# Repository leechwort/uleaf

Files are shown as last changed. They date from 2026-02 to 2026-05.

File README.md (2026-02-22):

# uLEAF

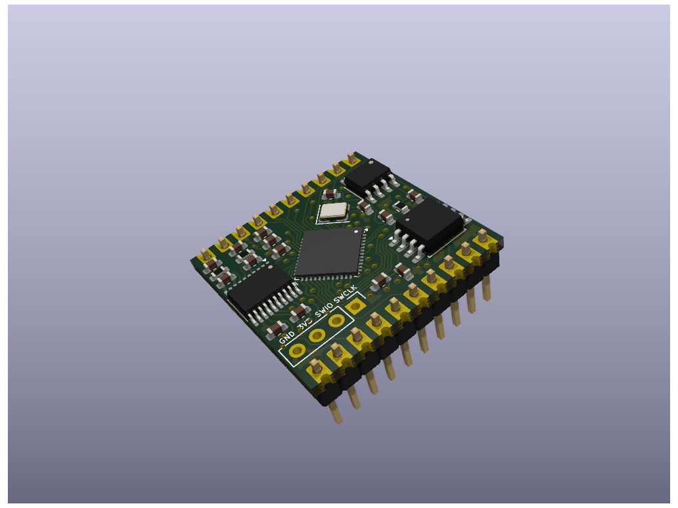
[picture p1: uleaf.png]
uLEAF Development Board


**uLEAF** is a minimalistic STM32 platform for developing audio synthesis applications. It was primarily designed for use with [LEAF (Lightweight Embedded Audio Framework)](https://github.com/spiricom/LEAF), but is not limited to it. 

### Hardware Features
* **Powerful MCU:** Cortex-M33 (STM32H533) with memory-mapped 8 MB PSRAM
* **Storage:** 8 MB additional external Flash memory
* **Audio:** Audio DAC PCM5102A

### Design Philosophy
This development board tries to be as cheap and simple as possible. It is designed to be highly versatile, allowing you to easily embed it directly into your own projects or use it as a starting point to develop your own custom PCB based on this design.

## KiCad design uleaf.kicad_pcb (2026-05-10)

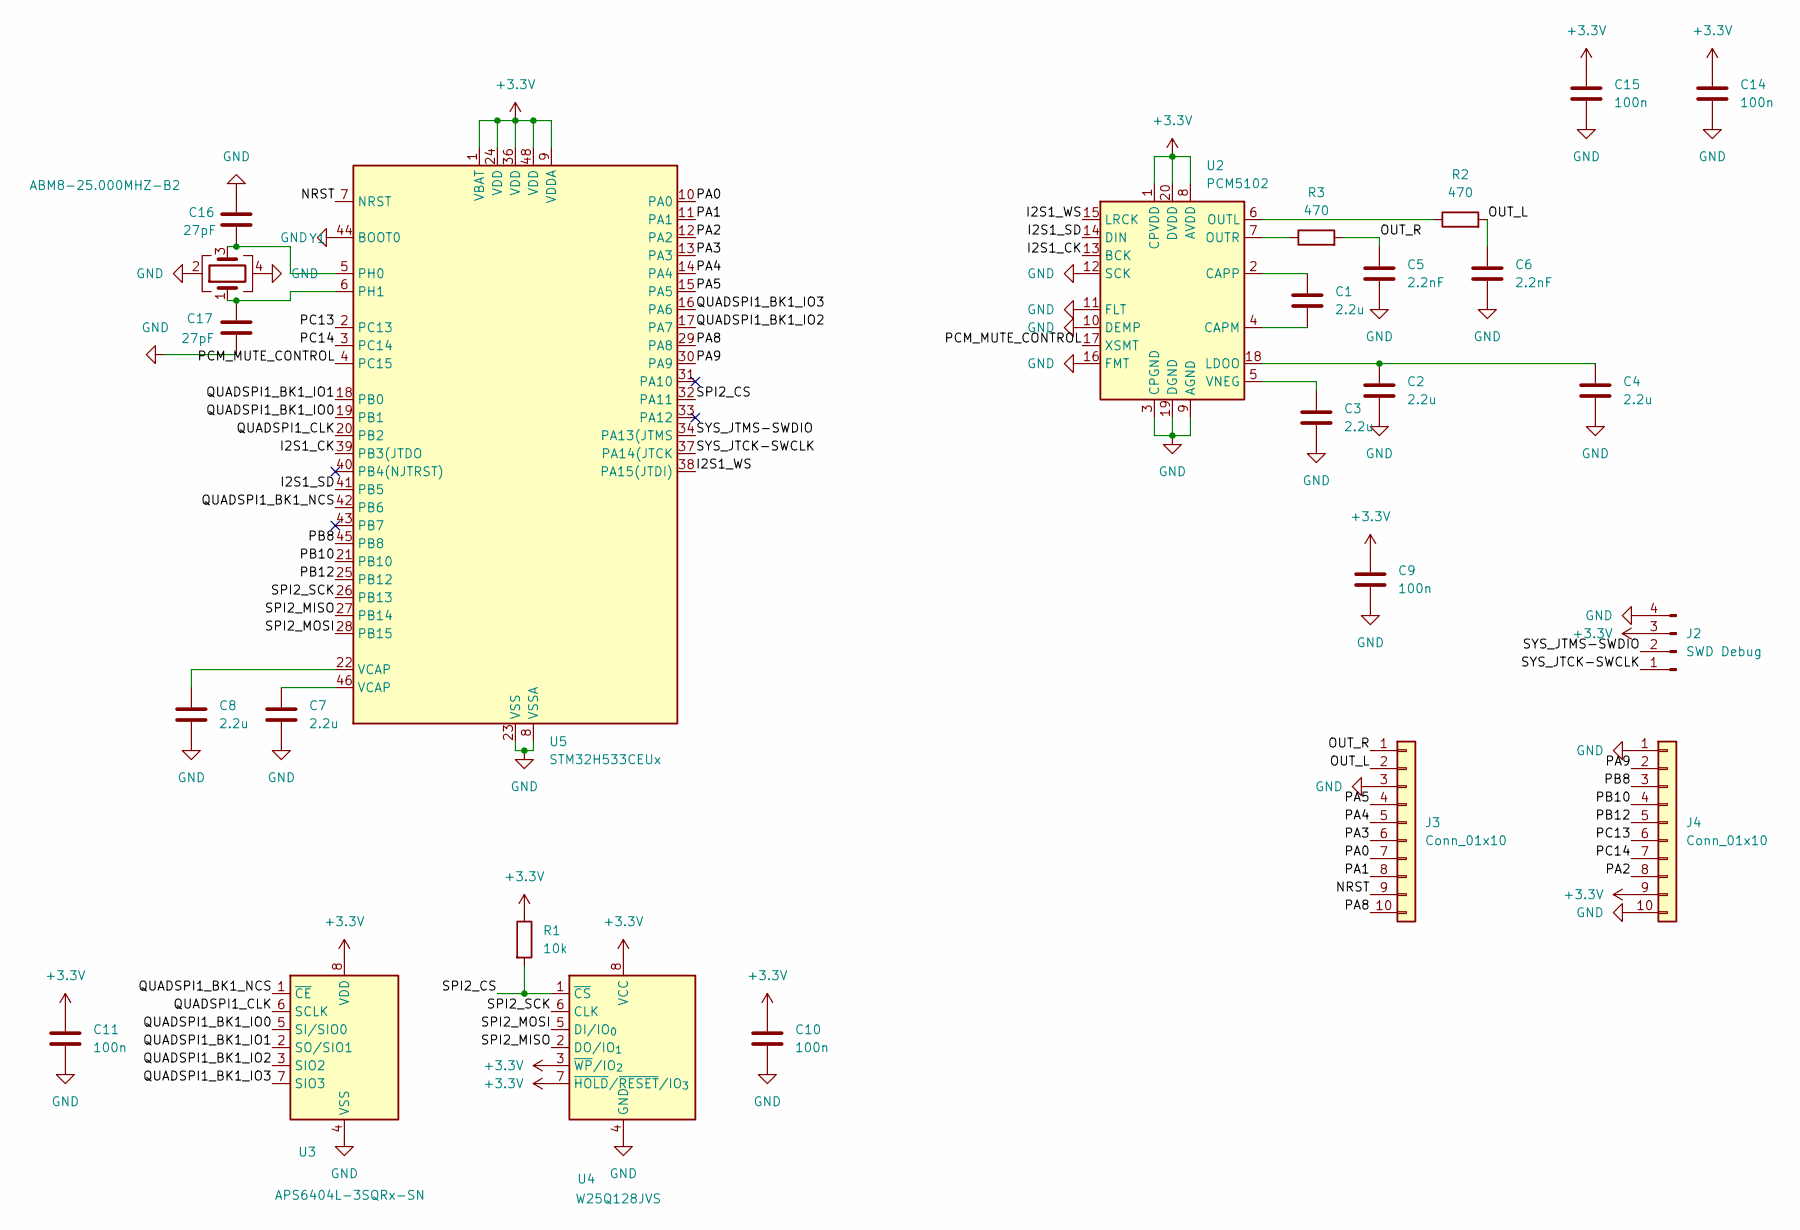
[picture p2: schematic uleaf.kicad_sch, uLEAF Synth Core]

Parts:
C1, C2, C3, C4, C7, C8: 2.2u; C_0603_1608Metric
C5, C6: 2.2nF; C_0603_1608Metric
C9, C10, C11, C14, C15: 100n; C_0603_1608Metric
C16, C17: 27pF; C_0603_1608Metric
J2: SWD Debug; PinHeader_1x04_P2.54mm_Vertical
J3, J4: Conn_01x10; PinHeader_1x10_P2.54mm_Vertical_Castellated
R1: 10k; R_0603_1608Metric
R2, R3: 470; R_0603_1608Metric
U2: PCM5102; TSSOP-20_4.4x6.5mm_P0.65mm
U3: APS6404L-3SQRx-SN; SOIC-8_3.9x4.9mm_P1.27mm
U4: W25Q128JVS; SOIC-8_5.3x5.3mm_P1.27mm
U5: STM32H533CEUx; QFN-48-1EP_7x7mm_P0.5mm_EP5.6x5.6mm
Y1: ABM8-25.000MHZ-B2; Crystal_SMD_3225-4Pin_3.2x2.5mm

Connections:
+3.3V: C9.2, C10.2, C11.2, C14.2, C15.2, J2.3, J4.9, R1.1, U2.1 (CPVDD), U2.8 (AVDD), U2.20 (DVDD), U3.8 (VDD), U4.3 (~WP/IO_{2}), U4.7 (~HOLD/~RESET/IO_{3}), U4.8 (VCC), U5.1 (VBAT), U5.9 (VDDA), U5.24 (VDD), U5.36 (VDD), U5.48 (VDD)
/I2S1_CK: U2.13 (BCK), U5.39 (PB3(JTDO)
/I2S1_SD: U2.14 (DIN), U5.41 (PB5)
/I2S1_WS: U2.15 (LRCK), U5.38 (PA15(JTDI))
/NRST: J3.9, U5.7 (NRST)
/OUT_L: C6.2, J3.2, R2.2
/OUT_R: C5.2, J3.1, R3.2
/PA0: J3.7, U5.10 (PA0)
/PA1: J3.8, U5.11 (PA1)
/PA2: J4.8, U5.12 (PA2)
/PA3: J3.6, U5.13 (PA3)
/PA4: J3.5, U5.14 (PA4)
/PA5: J3.4, U5.15 (PA5)
/PA8: J3.10, U5.29 (PA8)
/PA9: J4.2, U5.30 (PA9)
/PB8: J4.3, U5.45 (PB8)
/PB10: J4.4, U5.21 (PB10)
/PB12: J4.5, U5.25 (PB12)
/PC13: J4.6, U5.2 (PC13)
/PC14: J4.7, U5.3 (PC14)
/PCM_MUTE_CONTROL: U2.17 (XSMT), U5.4 (PC15)
/QUADSPI1_BK1_IO0: U3.5 (SI/SIO0), U5.19 (PB1)
/QUADSPI1_BK1_IO1: U3.2 (SO/SIO1), U5.18 (PB0)
/QUADSPI1_BK1_IO2: U3.3 (SIO2), U5.17 (PA7)
/QUADSPI1_BK1_IO3: U3.7 (SIO3), U5.16 (PA6)
/QUADSPI1_BK1_NCS: U3.1 (~CE), U5.42 (PB6)
/QUADSPI1_CLK: U3.6 (SCLK), U5.20 (PB2)
/SPI2_CS: R1.2, U4.1 (~CS), U5.32 (PA11)
/SPI2_MISO: U4.2 (DO/IO_{1}), U5.27 (PB14)
/SPI2_MOSI: U4.5 (DI/IO_{0}), U5.28 (PB15)
/SPI2_SCK: U4.6 (CLK), U5.26 (PB13)
/SYS_JTCK-SWCLK: J2.1, U5.37 (PA14(JTCK)
/SYS_JTMS-SWDIO: J2.2, U5.34 (PA13(JTMS)
GND: C2.1, C3.1, C4.1, C5.1, C6.1, C7.1, C8.1, C9.1, C10.1, C11.1, C14.1, C15.1, C16.2, C17.1, J2.4, J3.3, J4.1, J4.10, U2.3 (CPGND), U2.9 (AGND), U2.10 (DEMP), U2.11 (FLT), U2.12 (SCK), U2.16 (FMT), U2.19 (DGND), U3.4 (VSS), U4.4 (GND), U5.8 (VSSA), U5.23 (VSS), U5.35 (VSS), U5.44 (BOOT0), U5.47 (VSS), U5.49 (VSS), Y1.2, Y1.4
unnamed: C7.2, U5.46 (VCAP)
unnamed: C8.2, U5.22 (VCAP)
unnamed: C1.1, U2.4 (CAPM)
unnamed: C1.2, U2.2 (CAPP)
unnamed: C2.2, C4.2, U2.18 (LDOO)
unnamed: R2.1, U2.6 (OUTL)
unnamed: R3.1, U2.7 (OUTR)
unnamed: C3.2, U2.5 (VNEG)
unnamed: C16.1, U5.5 (PH0), Y1.3
unnamed: C17.2, U5.6 (PH1), Y1.1

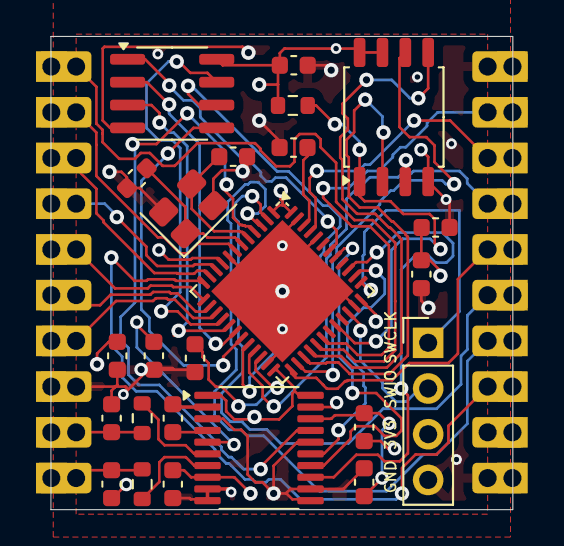
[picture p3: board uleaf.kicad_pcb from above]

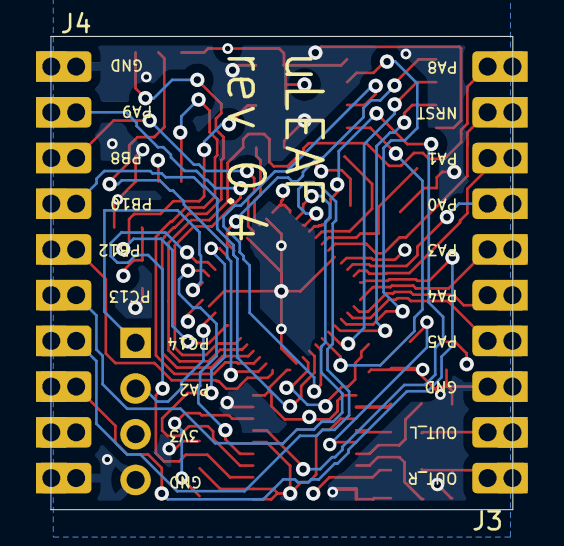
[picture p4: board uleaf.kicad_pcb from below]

Board: 4 copper layers, 25.7 x 26.3 mm, 26 parts (2 on the bottom side), 44 nets.

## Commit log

2025-11-27 Added project files
    [uleaf.kicad_pcb, uleaf.kicad_sch]
2026-02-14 Fixed problem with VNEG pin
    [uleaf.kicad_pcb, uleaf.kicad_sch]
2026-02-22 Fixed problem with output DAC output filters
    [uleaf.kicad_pcb, uleaf.kicad_sch]
2026-02-22 Added 3d model
    [uleaf.kicad_pcb]
2026-03-07 Added values for crystal and caps
    [uleaf.kicad_sch]
2026-05-10 Fixed problems with pcm connections, rev 0.4
    [uleaf.kicad_pcb, uleaf.kicad_sch]
